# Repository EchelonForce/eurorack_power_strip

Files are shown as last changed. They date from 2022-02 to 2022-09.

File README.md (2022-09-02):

# Eurorack Power Strip

This is a PCB for power distribution for eurorack.

Full writeup here: https://www.robotdialogs.com/2022/09/eurorack-power-distribution-pcb.html

This work is licensed under a Creative Commons Attribution-NonCommercial-ShareAlike 4.0 International License. https://creativecommons.org/licenses/by-nc-sa/4.0/

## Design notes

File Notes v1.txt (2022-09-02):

V1 boards ordered w/ 2oz copper.
First assembly was a bit tough at 400C the copper planes suck up heat. 
Next assembly will try preheating PCB with heat gun while soldering.

Changes to make
-10k resistors on schematic (no values on v1)

Assembly Order
 - Resistors
 - LEDs
 - 2x5 and 2x8 sockets, only 1/2 pins on CV/Gate lines (lower heat sink capacity)
 - Caps on +/- 12 Rails (lower heat sink capacity)
 - Finish soldering all pins

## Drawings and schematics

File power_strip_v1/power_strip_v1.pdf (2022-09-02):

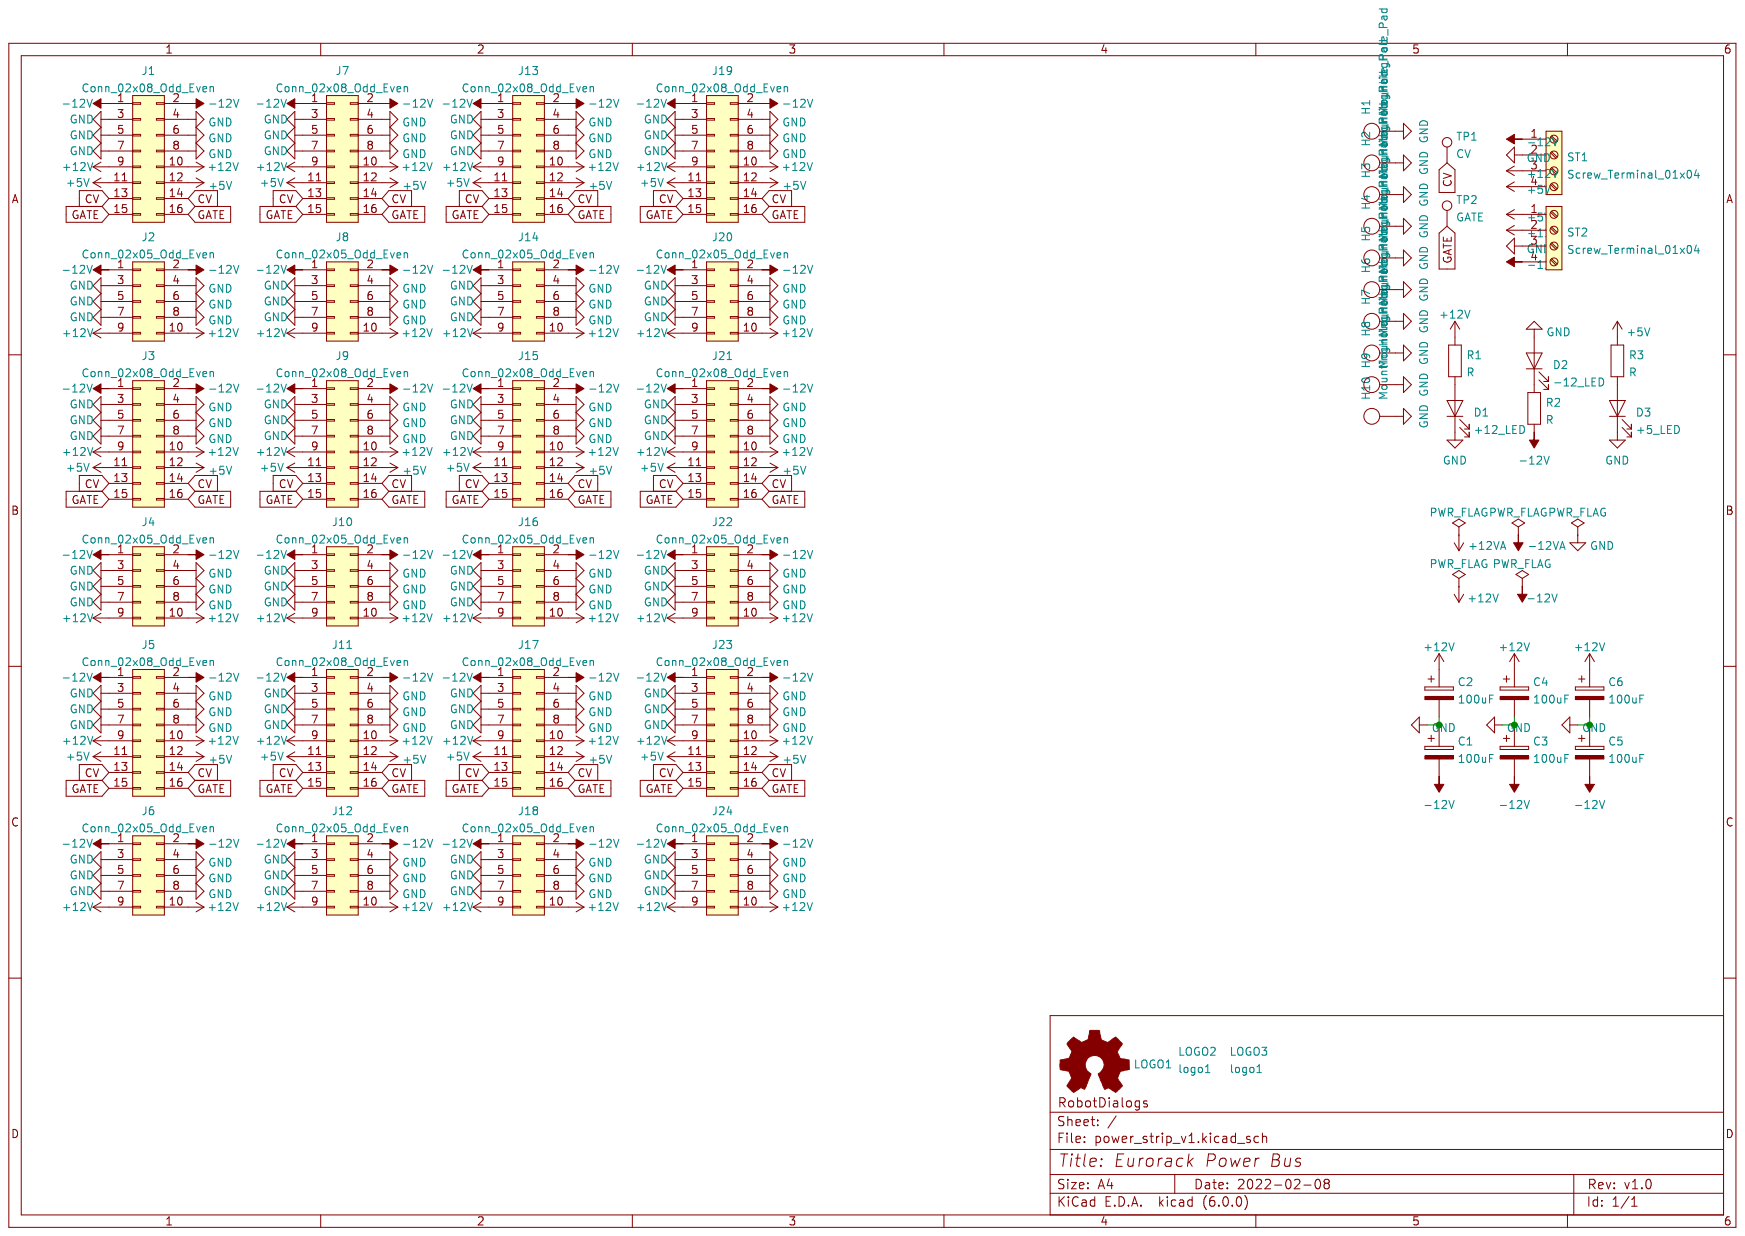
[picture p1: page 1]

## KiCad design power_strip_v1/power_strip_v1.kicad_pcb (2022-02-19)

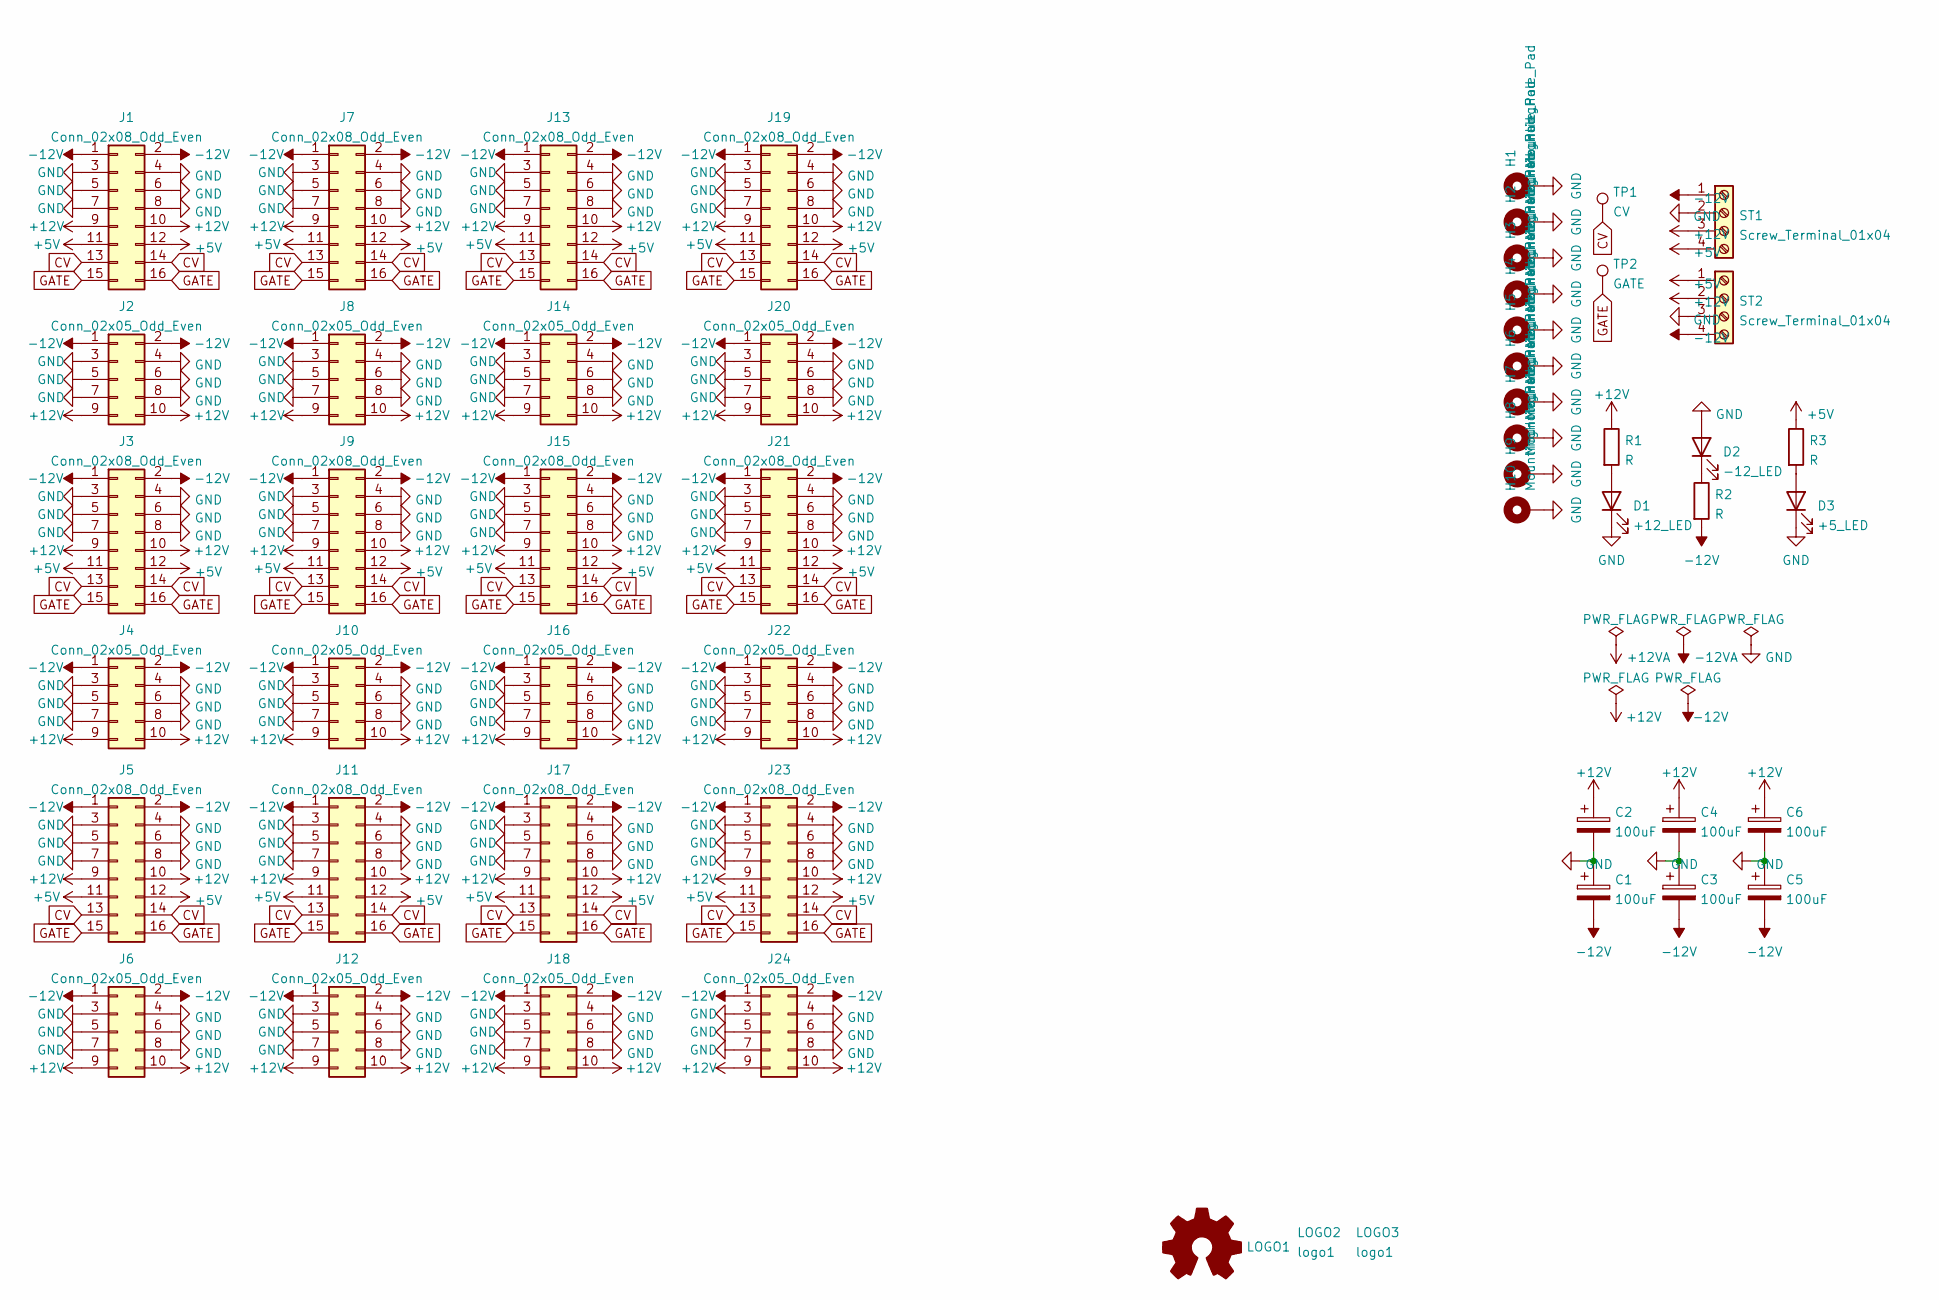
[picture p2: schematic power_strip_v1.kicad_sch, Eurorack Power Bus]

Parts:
C1, C2, C3, C4, C5, C6: 100uF; CP_Radial_D5.0mm_P2.50mm
D1: +12_LED; LED_D3.0mm
D2: -12_LED; LED_D3.0mm
D3: +5_LED; LED_D3.0mm
H1, H2, H3, H4, H5, H6, H7, H8, H9, H10: MountingHole_Pad; MountingHole_3.5mm_Pad_TopBottom
J1, J3, J5, J7, J9, J11, J13, J15, J17, J19, J21, J23: Conn_02x08_Odd_Even; IDC-Header_2x08_P2.54mm_Vertical
J2, J4, J6, J8, J10, J12, J14, J16, J18, J20, J22, J24: Conn_02x05_Odd_Even; IDC-Header_2x05_P2.54mm_Vertical
LOGO1: Logo_Open_Hardware_Small; OSHW-Symbol_6.7x6mm_SilkScreen
LOGO2: logo1; Logo1
LOGO3: logo1; Logo2
R1, R2, R3: R; R_Axial_DIN0204_L3.6mm_D1.6mm_P7.62mm_Horizontal
ST1, ST2: Screw_Terminal_01x04; TerminalBlock_Phoenix_MKDS-1,5-4_1x04_P5.00mm_Horizontal
TP1: CV; TestPoint_THTPad_D2.5mm_Drill1.2mm
TP2: GATE; TestPoint_THTPad_D2.5mm_Drill1.2mm

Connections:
+5V: J1.11, J1.12, J3.11, J3.12, J5.11, J5.12, J7.11, J7.12, J9.11, J9.12, J11.11, J11.12, J13.11, J13.12, J15.11, J15.12, J17.11, J17.12, J19.11, J19.12, J21.11, J21.12, J23.11, J23.12, R3.1, ST1.4, ST2.1
+12V: C2.1, C4.1, C6.1, J1.9, J1.10, J2.9, J2.10, J3.9, J3.10, J4.9, J4.10, J5.9, J5.10, J6.9, J6.10, J7.9, J7.10, J8.9, J8.10, J9.9, J9.10, J10.9, J10.10, J11.9, J11.10, J12.9, J12.10, J13.9, J13.10, J14.9, J14.10, J15.9, J15.10, J16.9, J16.10, J17.9, J17.10, J18.9, J18.10, J19.9, J19.10, J20.9, J20.10, J21.9, J21.10, J22.9, J22.10, J23.9, J23.10, J24.9, J24.10, R1.1, ST1.3, ST2.2
-12V: C1.2, C3.2, C5.2, J1.1, J1.2, J2.1, J2.2, J3.1, J3.2, J4.1, J4.2, J5.1, J5.2, J6.1, J6.2, J7.1, J7.2, J8.1, J8.2, J9.1, J9.2, J10.1, J10.2, J11.1, J11.2, J12.1, J12.2, J13.1, J13.2, J14.1, J14.2, J15.1, J15.2, J16.1, J16.2, J17.1, J17.2, J18.1, J18.2, J19.1, J19.2, J20.1, J20.2, J21.1, J21.2, J22.1, J22.2, J23.1, J23.2, J24.1, J24.2, R2.2, ST1.1, ST2.4
CV: J1.13, J1.14, J3.13, J3.14, J5.13, J5.14, J7.13, J7.14, J9.13, J9.14, J11.13, J11.14, J13.13, J13.14, J15.13, J15.14, J17.13, J17.14, J19.13, J19.14, J21.13, J21.14, J23.13, J23.14, TP1.1
GATE: J1.15, J1.16, J3.15, J3.16, J5.15, J5.16, J7.15, J7.16, J9.15, J9.16, J11.15, J11.16, J13.15, J13.16, J15.15, J15.16, J17.15, J17.16, J19.15, J19.16, J21.15, J21.16, J23.15, J23.16, TP2.1
GND: C1.1, C2.2, C3.1, C4.2, C5.1, C6.2, D1.1 (K), D2.2 (A), D3.1 (K), H1.1, H2.1, H3.1, H4.1, H5.1, H6.1, H7.1, H8.1, H9.1, H10.1, J1.3, J1.4, J1.5, J1.6, J1.7, J1.8, J2.3, J2.4, J2.5, J2.6, J2.7, J2.8, J3.3, J3.4, J3.5, J3.6, J3.7, J3.8, J4.3, J4.4, J4.5, J4.6, J4.7, J4.8, J5.3, J5.4, J5.5, J5.6, J5.7, J5.8, J6.3, J6.4, J6.5, J6.6, J6.7, J6.8, J7.3, J7.4, J7.5, J7.6, J7.7, J7.8, J8.3, J8.4, J8.5, J8.6, J8.7, J8.8, J9.3, J9.4, J9.5, J9.6, J9.7, J9.8, J10.3, J10.4, J10.5, J10.6, J10.7, J10.8, J11.3, J11.4, J11.5, J11.6, J11.7, J11.8, J12.3, J12.4, J12.5, J12.6, J12.7, J12.8, J13.3, J13.4, J13.5, J13.6, J13.7, J13.8, J14.3, J14.4, J14.5, J14.6, J14.7, J14.8, J15.3, J15.4, J15.5, J15.6, J15.7, J15.8, J16.3, J16.4, J16.5, J16.6, J16.7, J16.8, J17.3, J17.4, J17.5, J17.6, J17.7, J17.8, J18.3, J18.4, J18.5, J18.6, J18.7, J18.8, J19.3, J19.4, J19.5, J19.6, J19.7, J19.8, J20.3, J20.4, J20.5, J20.6, J20.7, J20.8, J21.3, J21.4, J21.5, J21.6, J21.7, J21.8, J22.3, J22.4, J22.5, J22.6, J22.7, J22.8, J23.3, J23.4, J23.5, J23.6, J23.7, J23.8, J24.3, J24.4, J24.5, J24.6, J24.7, J24.8, ST1.2, ST2.3
unnamed: D1.2 (A), R1.2
unnamed: D2.1 (K), R2.1
unnamed: D3.2 (A), R3.2

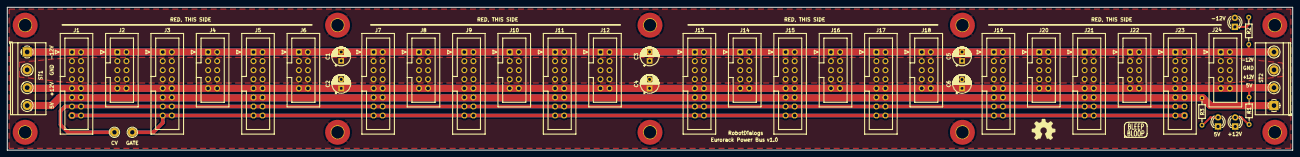
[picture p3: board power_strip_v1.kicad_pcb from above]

Board: 2 copper layers, 360.0 x 40.0 mm, 53 parts (0 on the bottom side), 9 nets.

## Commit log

2022-02-19 Version 1 PCB as ordered
    [power_strip_v1.kicad_pcb, power_strip_v1.kicad_sch]
2022-09-02 Notes and schematic v1 pdf
